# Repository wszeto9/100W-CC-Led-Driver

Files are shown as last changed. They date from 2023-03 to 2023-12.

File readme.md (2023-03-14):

# 100W RGB LED Constant Current Driver
A constant current driver made to to drive 100W RGB COB LEDs

[Interactive BOM](https://htmlpreview.github.io/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)

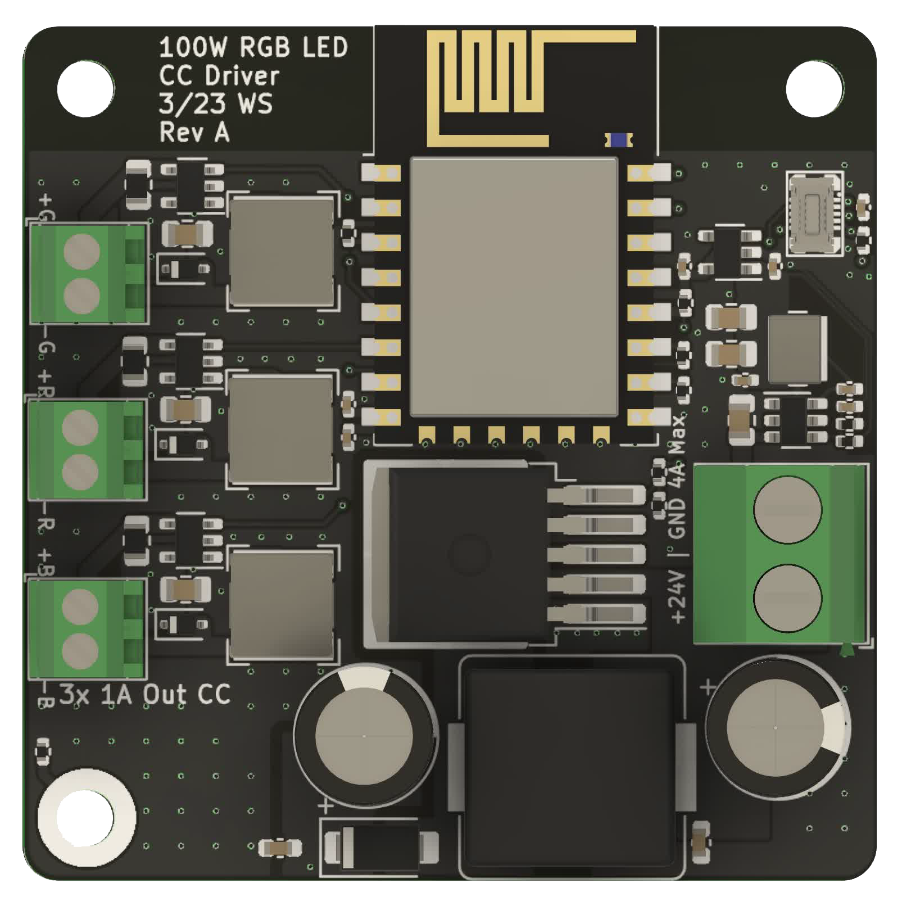
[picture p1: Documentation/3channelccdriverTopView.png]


<h2> Features:</h2>
<ul>

<li>3 Constant current outputs for Red, Green, and Blue channel</li>
<li>Controlled with an ESP8266 running WLED and connected over Wi-Fi</li>
<li>Panelized in a 2x2 panel of 100x100mm for minimal fabrication costs at JLCPCB</li>
<li>BOM cost is kept low at around $6 per board
</ul>
<h2>Pinout</h2>

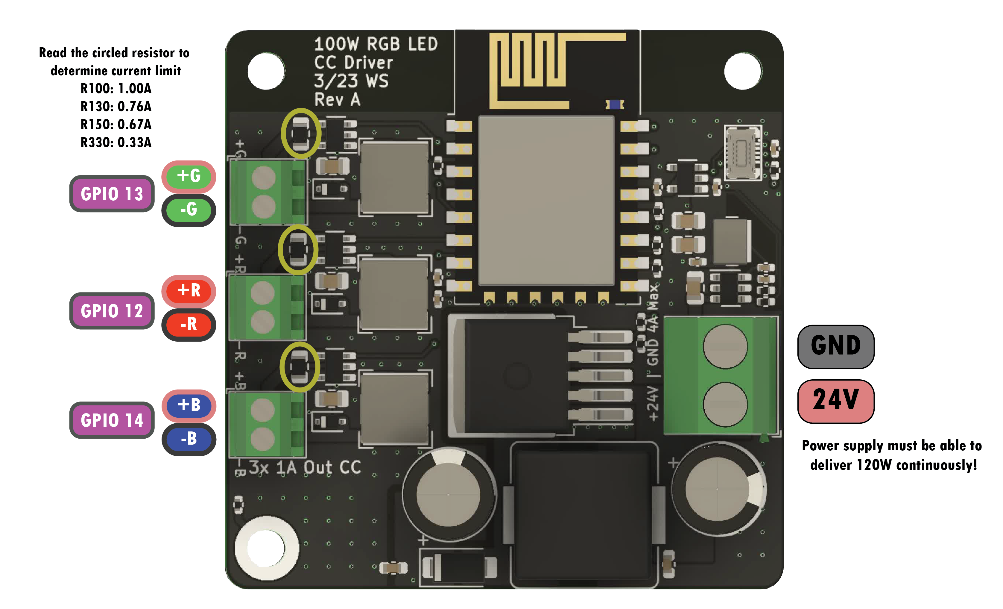
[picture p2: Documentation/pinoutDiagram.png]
Pinout


<h2> Bring-up and Usage </h2>

- Follow the iBOM and solder all items onto the board. 
- Attach the programming device onto the mezzamine connector on the top left of the board
- Program the ESP8266 with WLED
- Setup WLED with a single analog RGB channel attached to it. The pinouts should be:
    - Green: GPIO 13
    - Red: GPIO 12
    - Blue: GPIO 14
- Unplug the programming header and attach the LED and a 24V/5A power supply to the screw terminals
- Connect to the ESP's Wi-Fi network and turn on the lights!

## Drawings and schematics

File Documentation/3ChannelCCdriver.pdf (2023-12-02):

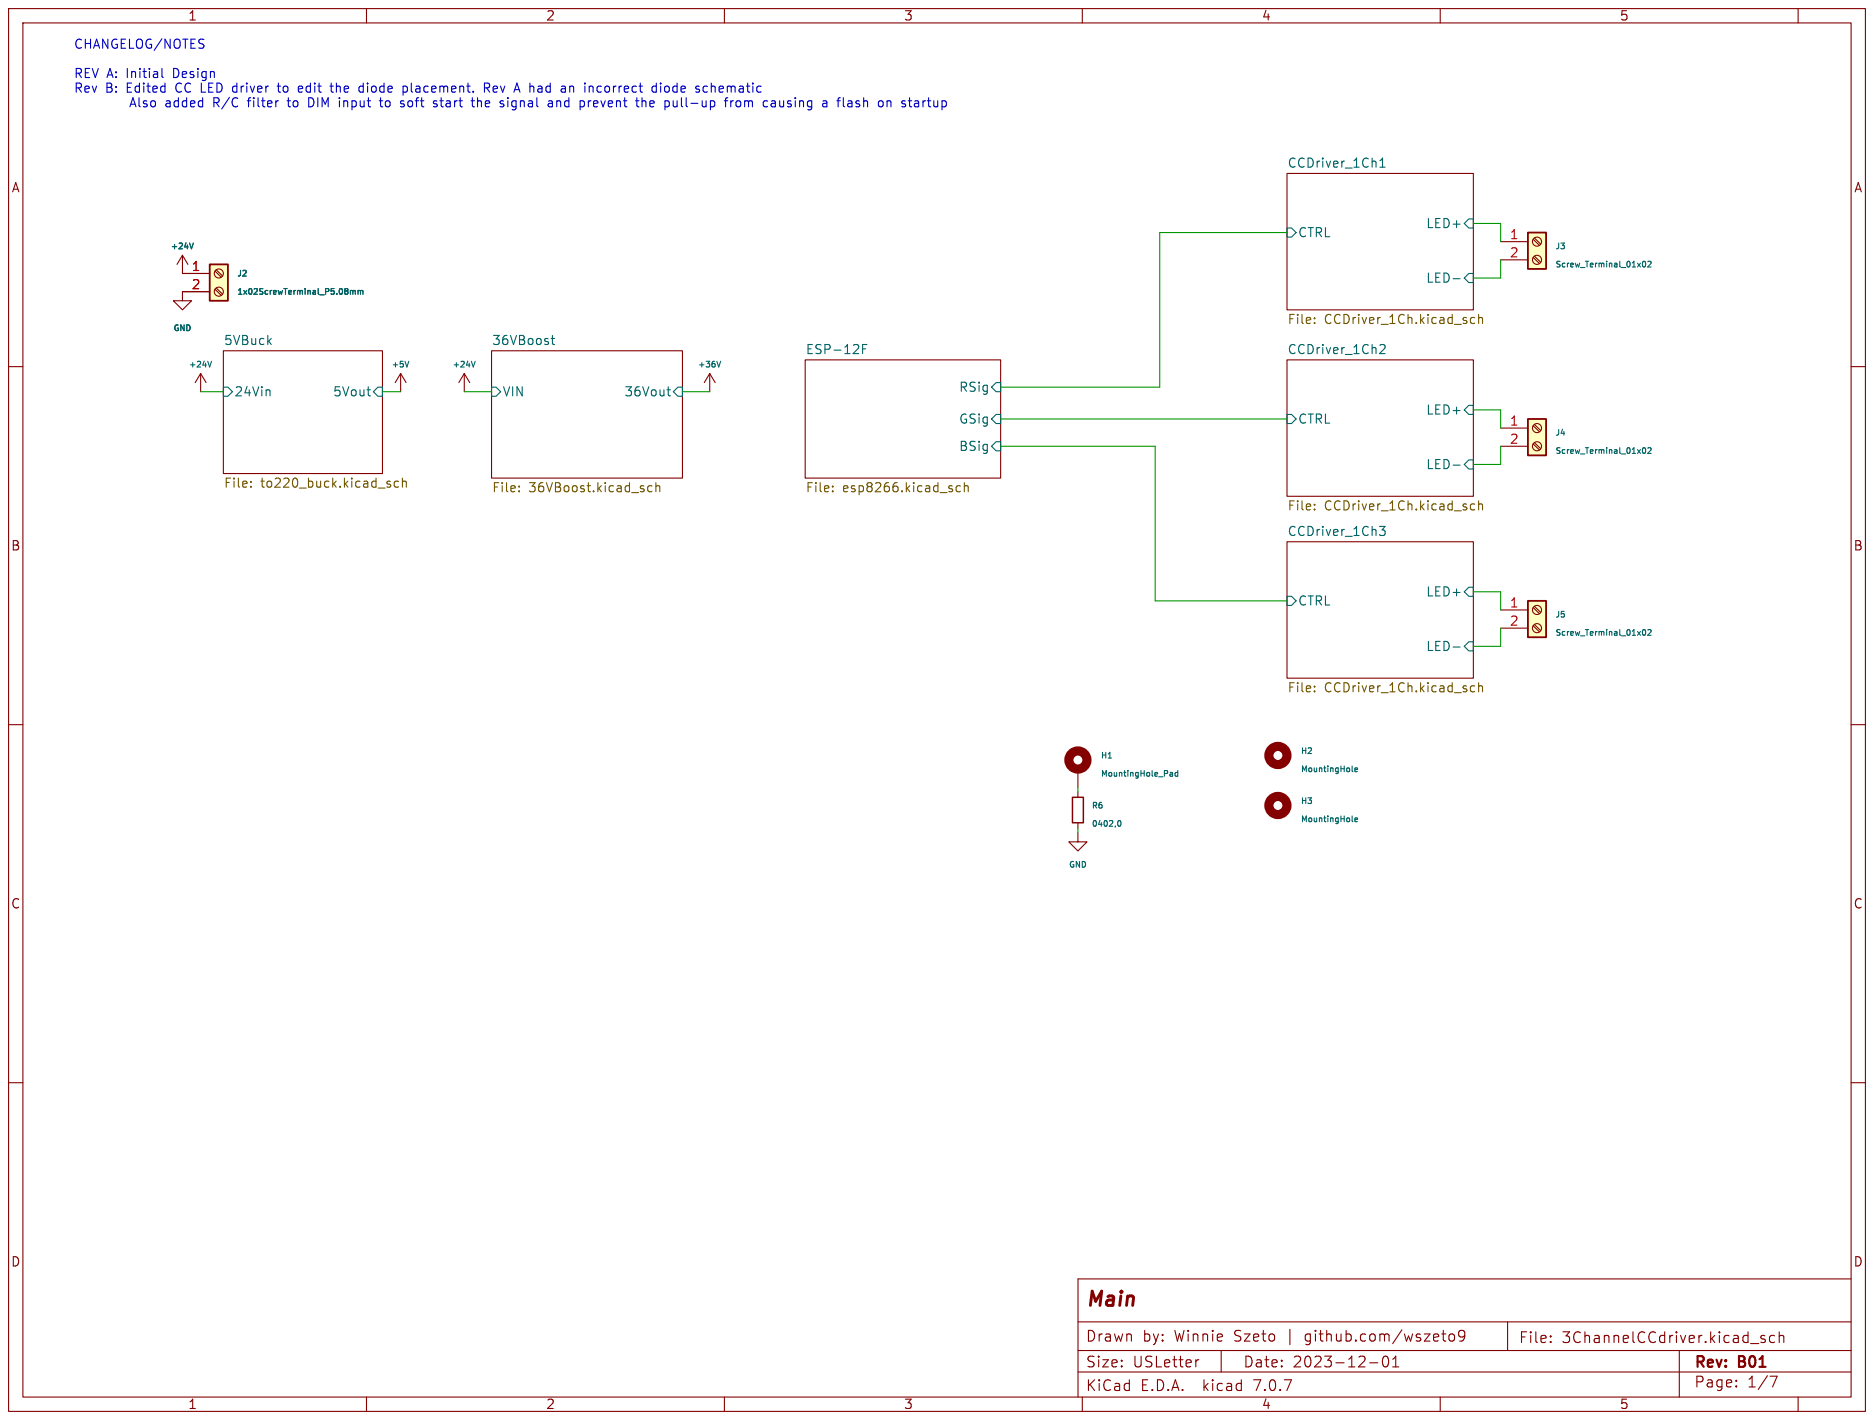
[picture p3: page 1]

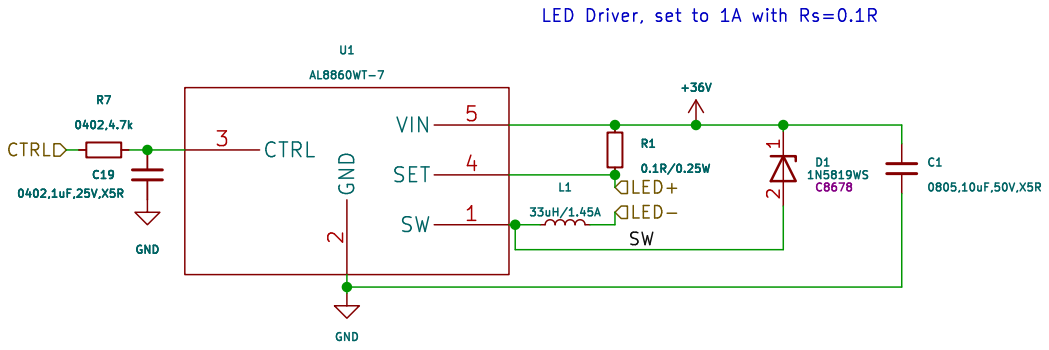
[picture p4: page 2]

LED Driver, set to 1A with Rs=0.1R

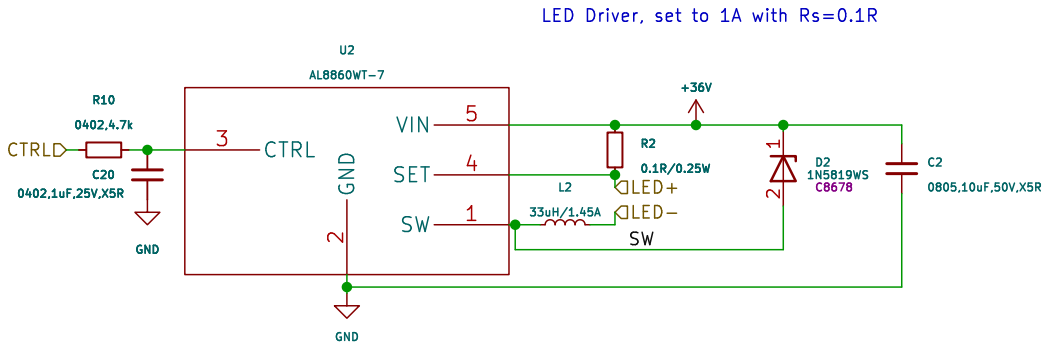
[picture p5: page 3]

LED Driver, set to 1A with Rs=0.1R

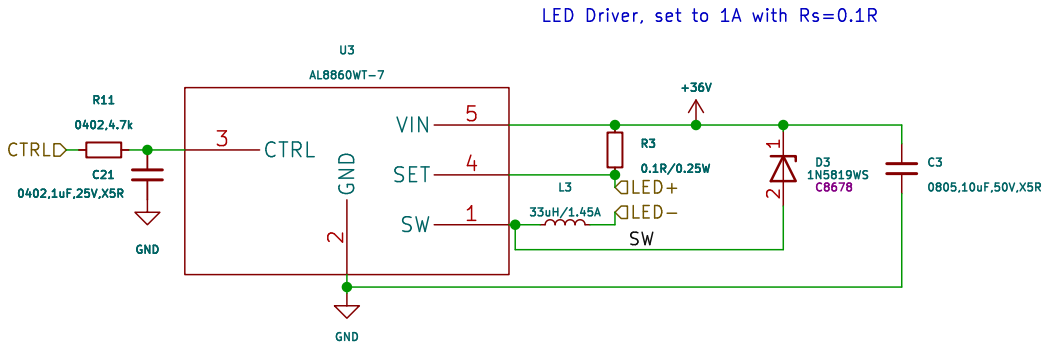
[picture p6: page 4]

LED Driver, set to 1A with Rs=0.1R

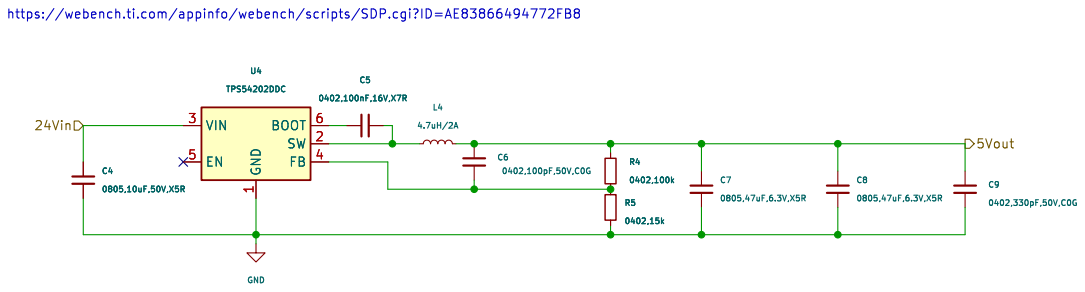
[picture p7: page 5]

https://webench.ti.com/appinfo/webench/scripts/SDP.cgi?ID=AE83866494772FB8

1 SW 2 VIN 3 FB 4 EN 5 BOOT 6

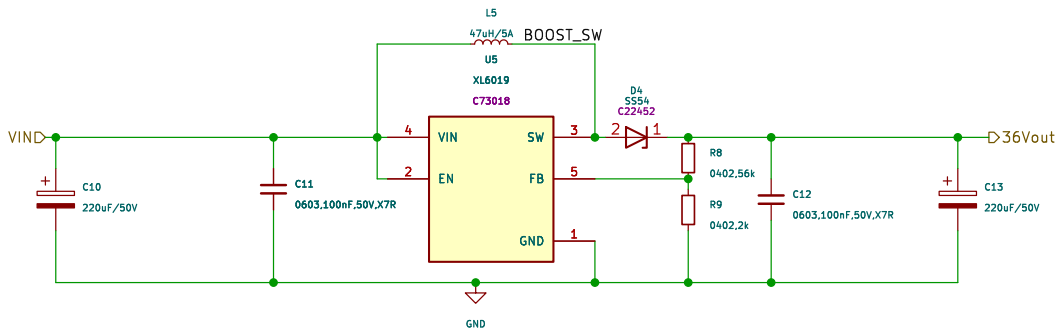
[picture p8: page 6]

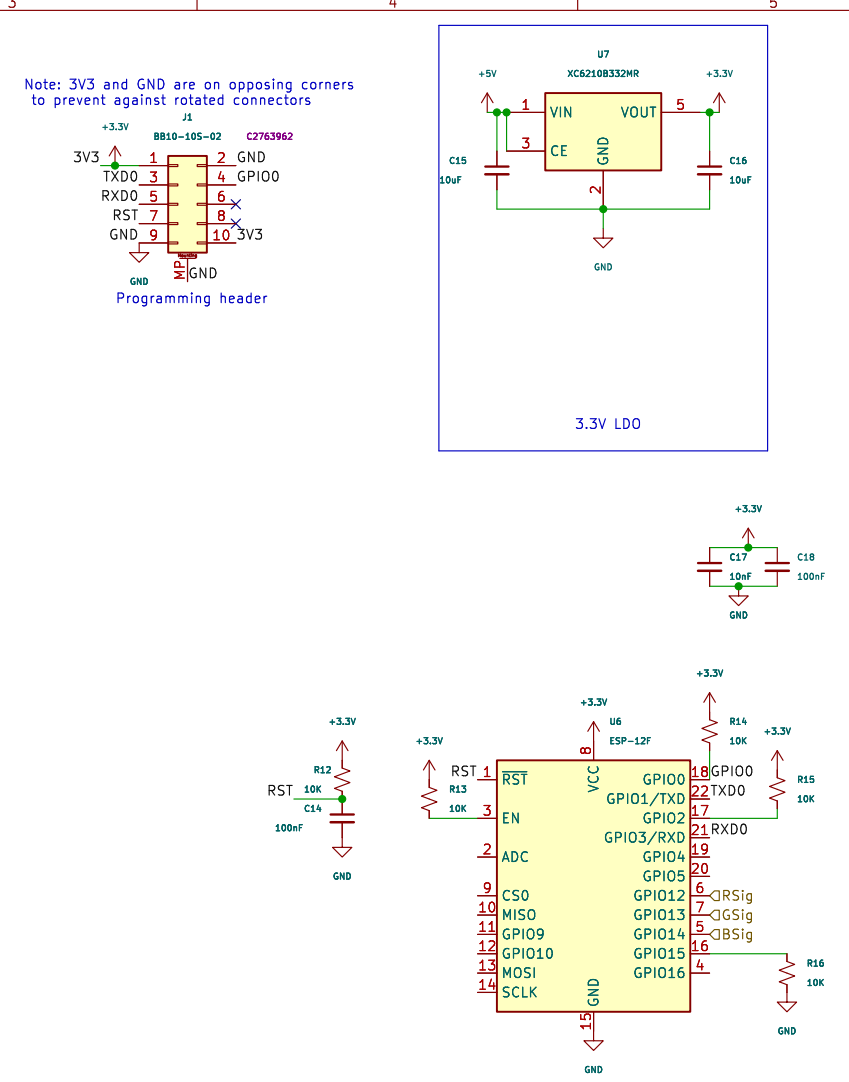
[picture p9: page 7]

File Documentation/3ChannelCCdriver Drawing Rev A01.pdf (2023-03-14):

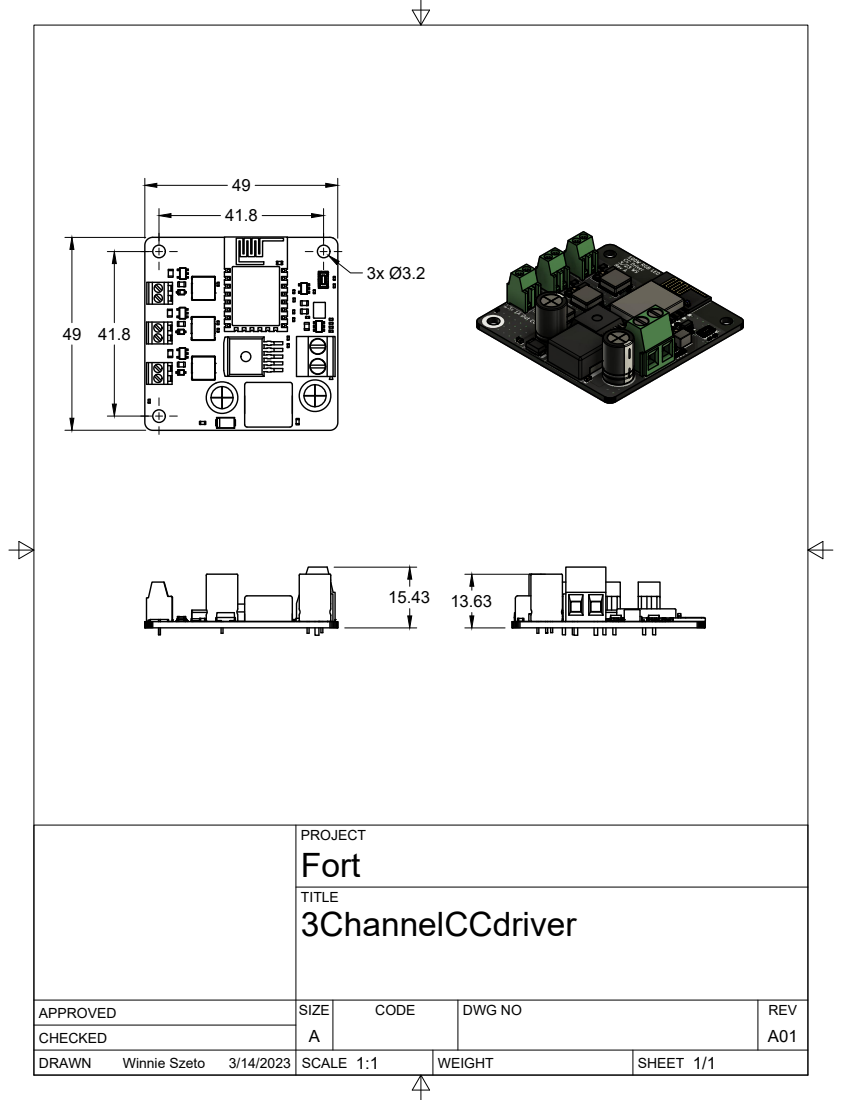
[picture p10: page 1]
SIZE; CODE; DWG NO; REV; Winnie Szeto

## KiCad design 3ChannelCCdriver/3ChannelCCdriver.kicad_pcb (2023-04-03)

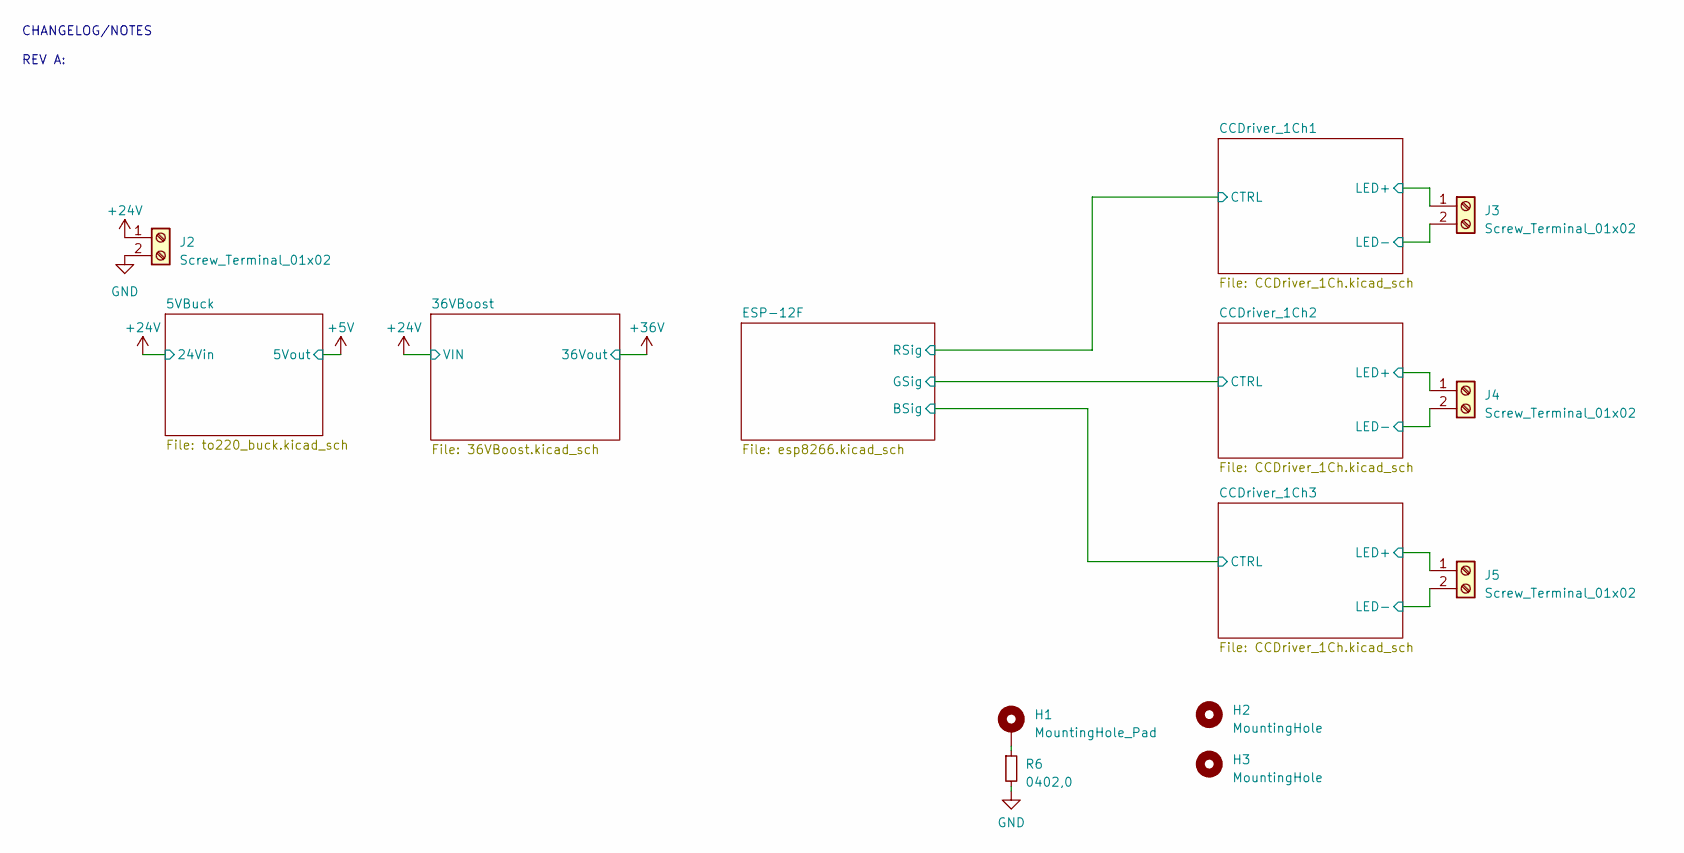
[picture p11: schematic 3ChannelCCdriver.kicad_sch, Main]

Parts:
H1: MountingHole_Pad; MountingHole_3.2mm_M3_DIN965_Pad
H2, H3: MountingHole; MountingHole_3.2mm_M3
J2: Screw_Terminal_01x02; TerminalBlock_Phoenix_MKDS-1,5-2-5.08_1x02_P5.08mm_Horizont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
J3, J4, J5: Screw_Terminal_01x02; TerminalBlock_TE_282834-2_1x02_P2.54mm_Horizontal; LCSC C2922597
R6: 0402,0; R_0402_1005Metric; MFGPN 0402WGF0000TCE; LCSC C17168

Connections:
+24V: J2.1; also elsewhere on the board
/CCDriver_1Ch1/LED+: J3.1; also elsewhere on the board
/CCDriver_1Ch1/LED-: J3.2; also elsewhere on the board
/CCDriver_1Ch2/LED+: J4.1; also elsewhere on the board
/CCDriver_1Ch2/LED-: J4.2; also elsewhere on the board
/CCDriver_1Ch3/LED+: J5.1; also elsewhere on the board
/CCDriver_1Ch3/LED-: J5.2; also elsewhere on the board
GND: J2.2, R6.2; also elsewhere on the board
unnamed: H1.1, R6.1

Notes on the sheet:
CHANGELOG/NOTES REV A:

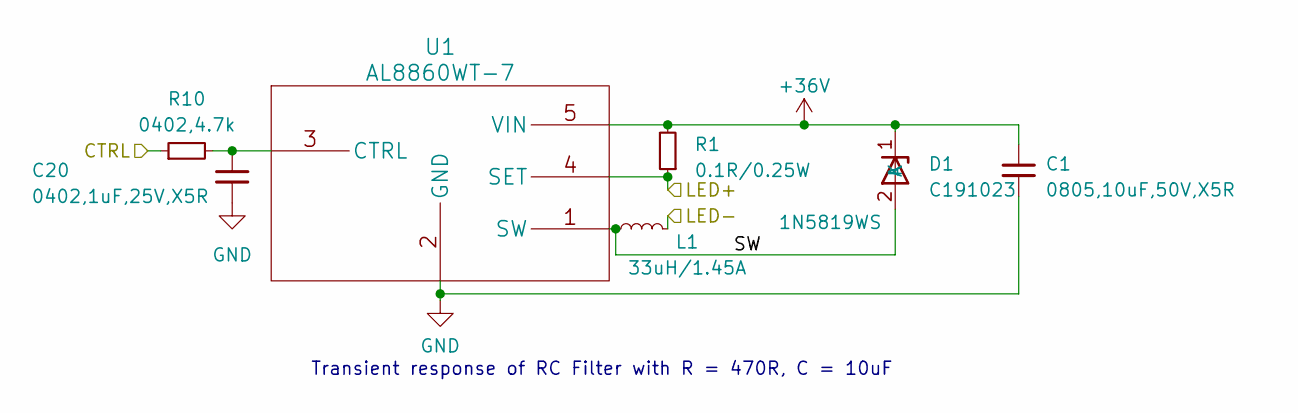
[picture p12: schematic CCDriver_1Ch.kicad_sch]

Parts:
C1: 0805,10uF,50V,X5R; C_0805_2012Metric; MFGPN GRM21BR61H106KE43L; LCSC C440198
C20: 0402,1uF,25V,X5R; C_0402_1005Metric; MFGPN CL05A105KA5NQNC; LCSC C52923
D1: 1N5819WS; D_SOD-323; LCSC C191023
L1: 33uH/1.45A; L_Bourns-SRN6028; LCSC C354635
R1: 0.1R/0.25W; R_0805_2012Metric; LCSC C171367
R10: 0402,4.7k; R_0402_1005Metric; MFGPN 0402WGF4701TCE; LCSC C25900
U1: AL8860WT-7; TSOT-23-5; LCSC C125330

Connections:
+36V: C1.1, D1.1 (K), R1.2, U1.5 (VIN); also elsewhere on the board
/CCDriver_1Ch1/CTRL: R10.1; also elsewhere on the board
/CCDriver_1Ch3/LED+: R1.1, U1.4 (SET); also elsewhere on the board
/CCDriver_1Ch3/LED-: L1.2; also elsewhere on the board
/CCDriver_1Ch3/SW: D1.2 (A), L1.1, U1.1 (SW)
GND: C1.2, C20.2, U1.2 (GND); also elsewhere on the board

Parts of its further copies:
C2, C3: 0805,10uF,50V,X5R; C_0805_2012Metric; MFGPN GRM21BR61H106KE43L; LCSC C440198
C19, C21: 0402,1uF,25V,X5R; C_0402_1005Metric; MFGPN CL05A105KA5NQNC; LCSC C52923
D2, D3: 1N5819WS; D_SOD-323; LCSC C191023
L2, L3: 33uH/1.45A; L_Bourns-SRN6028; LCSC C354635
R2, R3: 0.1R/0.25W; R_0805_2012Metric; LCSC C171367
R7, R11: 0402,4.7k; R_0402_1005Metric; MFGPN 0402WGF4701TCE; LCSC C25900
U2, U3: AL8860WT-7; TSOT-23-5; LCSC C125330

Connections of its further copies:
+36V: C2.1, C3.1, D2.1 (K), D3.1 (K), R2.2, R3.2, U2.5 (VIN), U3.5 (VIN); also elsewhere on the board
/CCDriver_1Ch1/LED+: R2.1, U2.4 (SET); also elsewhere on the board
/CCDriver_1Ch1/LED-: L2.2; also elsewhere on the board
/CCDriver_1Ch1/SW: D2.2 (A), L2.1, U2.1 (SW)
/CCDriver_1Ch2/CTRL: R11.1; also elsewhere on the board
/CCDriver_1Ch2/LED+: R3.1, U3.4 (SET); also elsewhere on the board
/CCDriver_1Ch2/LED-: L3.2; also elsewhere on the board
/CCDriver_1Ch2/SW: D3.2 (A), L3.1, U3.1 (SW)
/CCDriver_1Ch3/CTRL: R7.1; also elsewhere on the board
GND: C2.2, C3.2, C19.2, C21.2, U2.2 (GND), U3.2 (GND); also elsewhere on the board
unnamed: C21.1, R11.2, U3.3 (CTRL)

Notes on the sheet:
Transient response of RC Filter with R = 470R, C = 10uF

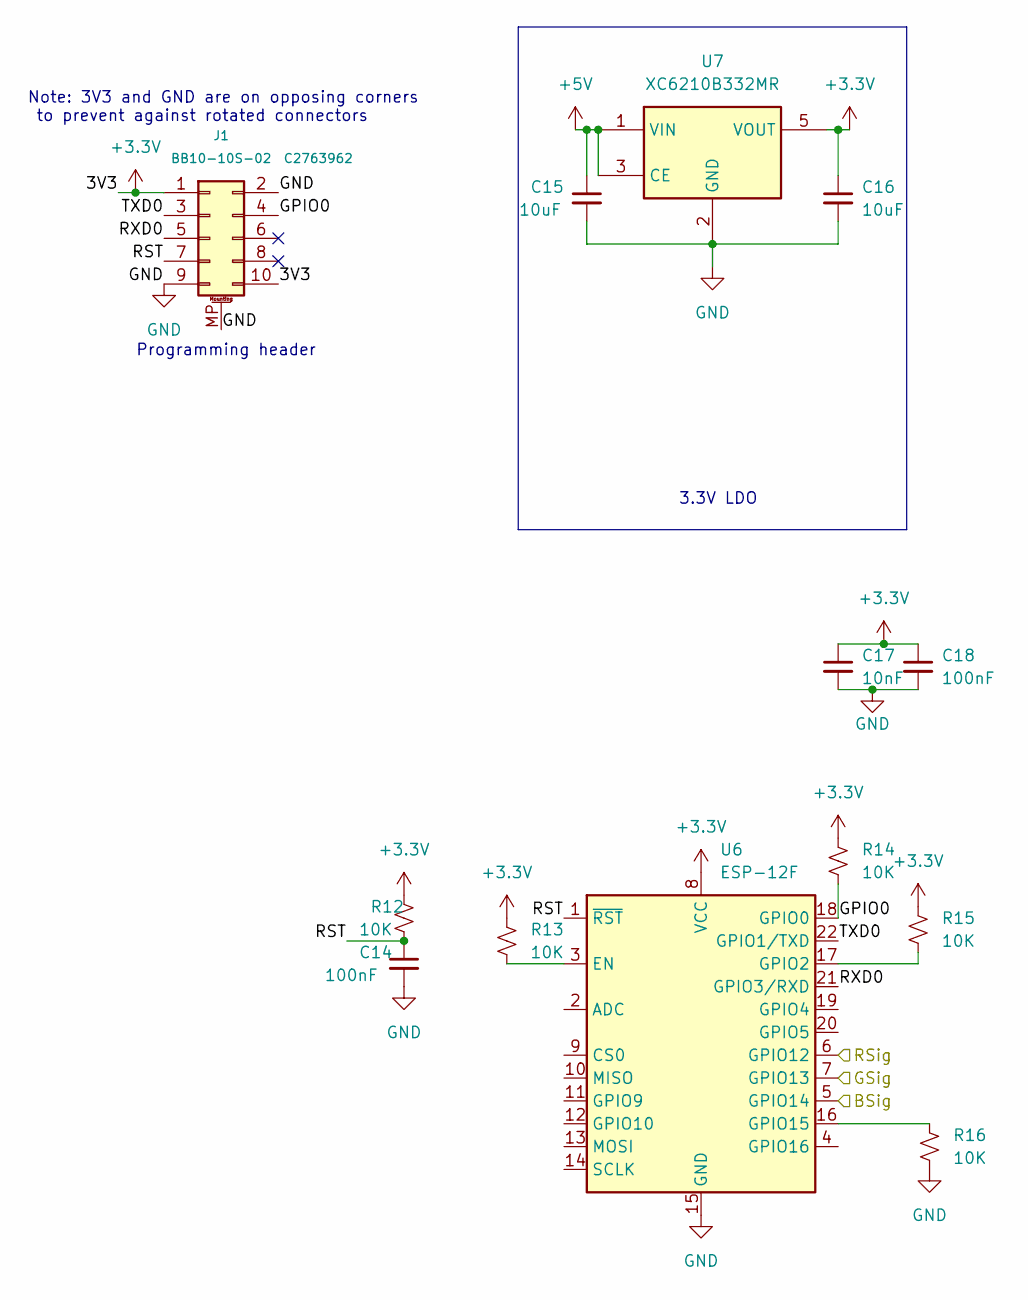
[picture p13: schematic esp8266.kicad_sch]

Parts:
C14, C18: 100nF; C_0402_1005Metric; LCSC Part Number C1525
C15, C16: 10uF; C_0402_1005Metric; LCSC Part Number C15525
C17: 10nF; C_0402_1005Metric; LCSC Part Number C15195
J1: BB10-10S-02; YXT-BB10-10S-02; LCSC C2763962
R12, R13, R14, R15, R16: 10K; R_0402_1005Metric; LCSC Part Number C25744
U6: ESP-12F; ESP-12E
U7: XC6210B332MR; SOT-23-5; LCSC Part Number C424705

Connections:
+3.3V: C16.1, C17.1, C18.1, J1.1, J1.10, R12.2, R13.2, R14.1, R15.1, U6.8 (VCC), U7.5 (VOUT)
+5V: C15.1, U7.1 (VIN), U7.3 (CE); also elsewhere on the board
/CCDriver_1Ch1/CTRL: U6.6 (GPIO12); also elsewhere on the board
/CCDriver_1Ch2/CTRL: U6.7 (GPIO13); also elsewhere on the board
/CCDriver_1Ch3/CTRL: U6.5 (GPIO14); also elsewhere on the board
/ESP-12F/GPIO0: J1.4, R14.2, U6.18 (GPIO0)
/ESP-12F/RST: C14.1, J1.7, R12.1, U6.1 (~RST)
/ESP-12F/RXD0: J1.5, U6.21 (GPIO3/RXD)
/ESP-12F/TXD0: J1.3, U6.22 (GPIO1/TXD)
GND: C14.2, C15.2, C16.2, C17.2, C18.2, J1.2, J1.9, J1.MP (MountPin), R16.2, U6.15 (GND), U7.2 (GND); also elsewhere on the board
unnamed: R13.1, U6.3 (EN)
unnamed: R15.2, U6.17 (GPIO2)
unnamed: R16.1, U6.16 (GPIO15)

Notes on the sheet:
Programming header
3.3V LDO
Note: 3V3 and GND are on opposing corners to prevent against rotated connectors

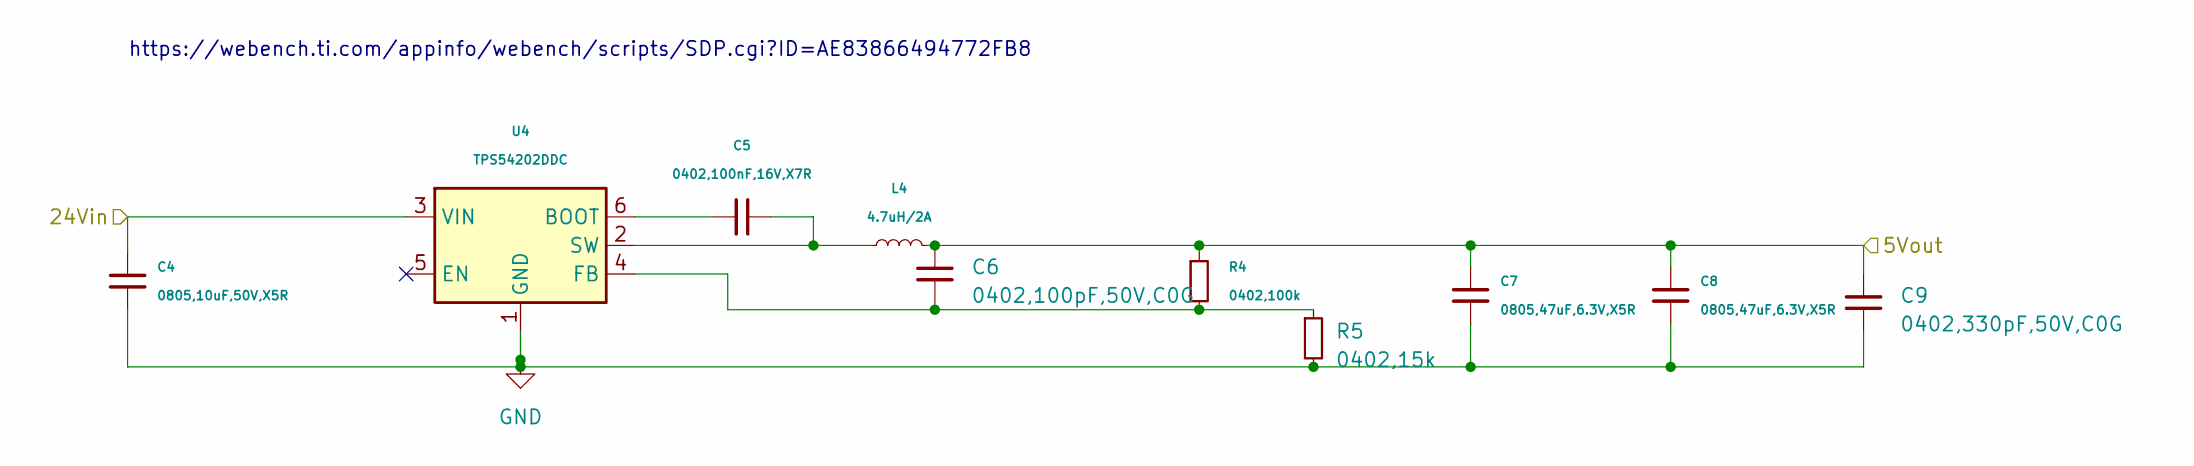
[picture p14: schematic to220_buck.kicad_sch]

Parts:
C4: 0805,10uF,50V,X5R; C_0805_2012Metric; MFGPN GRM21BR61H106KE43L; LCSC C440198
C5: 0402,100nF,16V,X7R; C_0402_1005Metric; MFGPN CL05B104KO5NNNC; LCSC C1525
C6: 0402,100pF,50V,C0G; C_0402_1005Metric; MFGPN 0402CG101J500NT; LCSC C1546
C7, C8: 0805,47uF,6.3V,X5R; C_0805_2012Metric; MFGPN CL21A476MQYNNNE; LCSC C16780
C9: 0402,330pF,50V,C0G; C_0402_1005Metric; MFGPN CL05C331JB5NNNC; LCSC C13533
L4: 4.7uH/2A; L_Wuerth_MAPI-4030; MFGPN YNR4030-4R7M; LCSC C340391
R4: 0402,100k; R_0402_1005Metric; MFGPN 0402WGF1003TCE; LCSC C25741
R5: 0402,15k; R_0402_1005Metric; MFGPN 0402WGF1502TCE; LCSC C25756
U4: TPS54202DDC; SOT-23-6; MFGPN TPS54202DDCR; LCSC C191884

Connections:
+5V: C6.1, C7.1, C8.1, C9.1, L4.2, R4.1; also elsewhere on the board
+24V: C4.1, U4.3 (VIN); also elsewhere on the board
GND: C4.2, C7.2, C8.2, C9.2, R5.2, U4.1 (GND); also elsewhere on the board
unnamed: C5.1, U4.6 (BOOT)
unnamed: C6.2, R4.2, R5.1, U4.4 (FB)
unnamed: C5.2, L4.1, U4.2 (SW)

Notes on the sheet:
https://webench.ti.com/appinfo/webench/scripts/SDP.cgi?ID=AE83866494772FB8

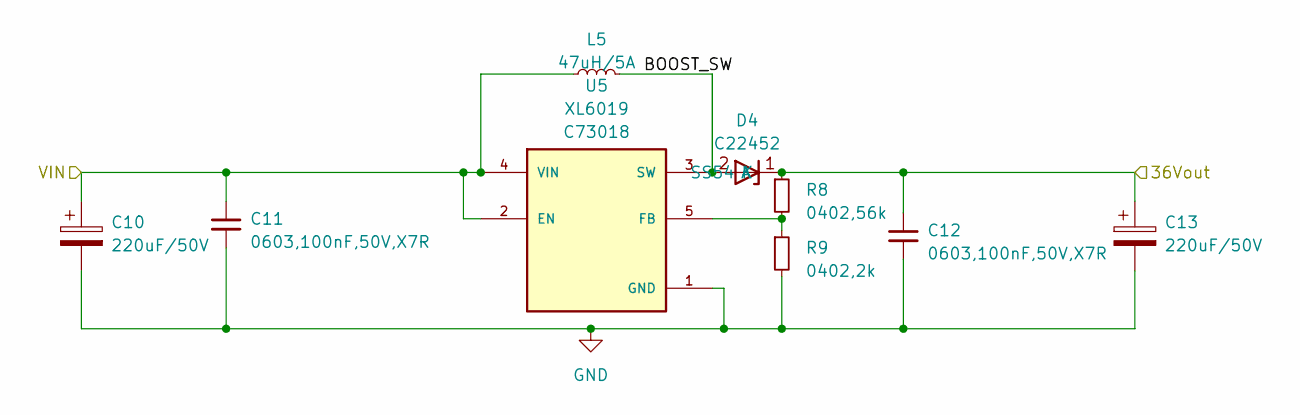
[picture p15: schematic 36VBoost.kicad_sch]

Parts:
C10, C13: 220uF/50V; CP_Radial_D8.0mm_P3.50mm; LCSC C2836445
C11, C12: 0603,100nF,50V,X7R; C_0603_1608Metric; MFGPN CC0603KRX7R9BB104; LCSC C2886384
D4: SS54; D_SMA; LCSC C22452
L5: 47uH/5A; L_Bourns_SRP1245A; LCSC C497913
R8: 0402,56k; R_0402_1005Metric; MFGPN 0402WGF5602TCE; LCSC C25796
R9: 0402,2k; R_0402_1005Metric; MFGPN 0402WGF2001TCE; LCSC C4109
U5: XL6019; TO-263-5_TabPin3; PARTREV 1.1; LCSC C73018

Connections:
+24V: C10.1, C11.1, L5.1, U5.2 (EN), U5.4 (VIN); also elsewhere on the board
+36V: C12.1, C13.1, D4.1 (K), R8.1; also elsewhere on the board
/36VBoost/BOOST_SW: D4.2 (A), L5.2, U5.3 (SW)
GND: C10.2, C11.2, C12.2, C13.2, R9.2, U5.1 (GND); also elsewhere on the board
unnamed: R8.2, R9.1, U5.5 (FB)

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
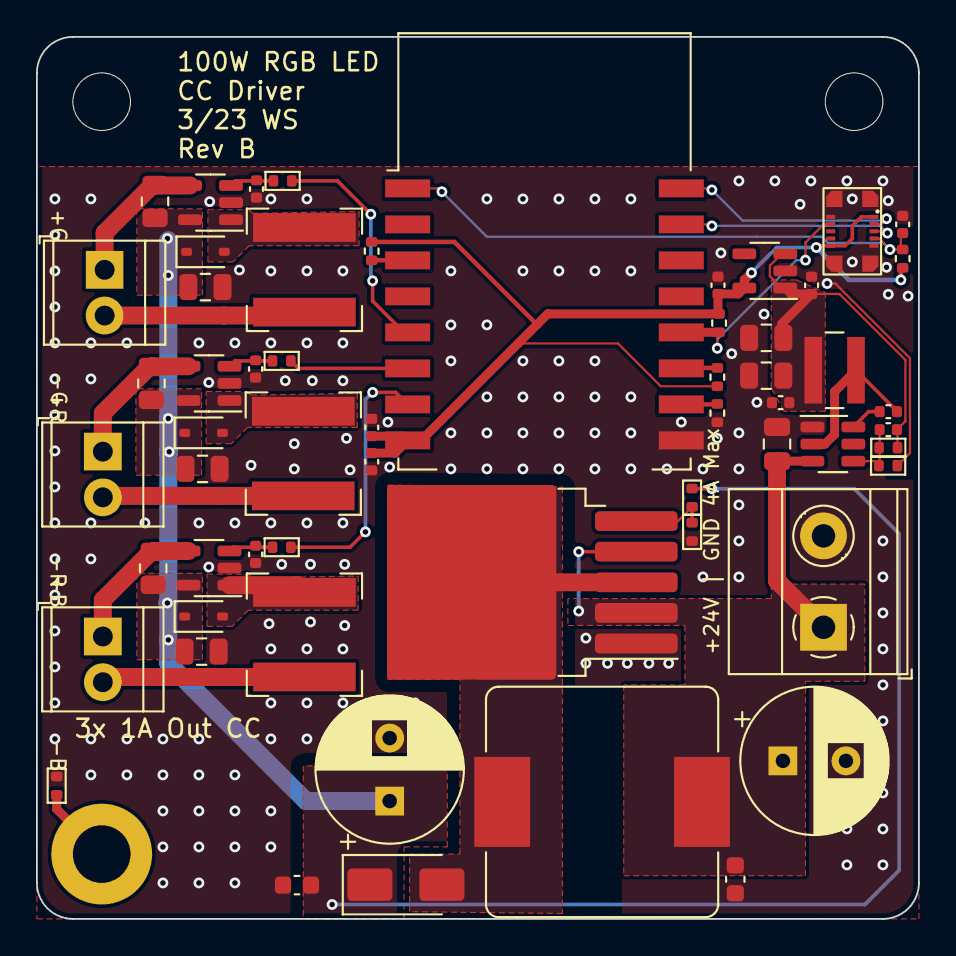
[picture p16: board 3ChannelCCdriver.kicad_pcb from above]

Board: 2 copper layers, 49.0 x 49.0 mm, 61 parts (0 on the bottom side), 33 nets.

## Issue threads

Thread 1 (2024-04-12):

LED Forward Voltage

kinisy, 2024-04-12:
I'm just wondering what LED you used as the output voltage of each CC Driver is 36V whereas the typical forward voltage of Red LED in a 100W COB LED is around 20-24V? Please let me know as interested in this design🙂

wszeto9, 2024-04-19:
https://www.aliexpress.us/item/2251832732091887.html

Nominal output is around 36V, but because it's a constant current driver, the buck will decrease the voltage to 24V to drive ~ 1A through the LED.

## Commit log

2023-03-07 laid out board
    [36VBoost.kicad_sch, 3ChannelCCdriver.kicad_pcb, 3ChannelCCdriver.kicad_sch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]
2023-03-14 Added documentation
    [3ChannelCCdriver.kicad_pcb, 3ChannelCCdriver.kicad_sch, 3ChannelCCdriver_panelized.kicad_pcb]
2023-04-03 Changed rev to B01
    Changed diode pinout on CC driver
    [36VBoost.kicad_sch, 3ChannelCCdriver.kicad_pcb, 3ChannelCCdriver.kicad_sch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]
2023-04-11 changed panelization
    [3ChannelCCdriver_panelized.kicad_pcb]
2023-12-02 neat-ified schematics
    [36VBoost.kicad_sch, 3ChannelCCdriver.kicad_sch, CCDriver_1Ch.kicad_sch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]
